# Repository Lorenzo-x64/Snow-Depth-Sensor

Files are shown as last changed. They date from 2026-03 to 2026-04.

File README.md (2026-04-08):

<div align="center">

  # Snow Depth Sensor

</div>

<div align="center">
  <picture>
    <source media="(prefers-color-scheme: dark)" srcset="https://github.com/lorenzor0912/Projet-IT-Neige/blob/0a817e1d05e45fb6e63a99a292cdd9ac2ce48b34/ReadMe_IMG/It%20neige.svg" />
    Logo principal
  </picture>

  <p><strong>Solution autonome de mesure d'enneigement pour environnements extrêmes</strong></p>

  <p>
    
    
    
    
  </p>
</div>

---

## Table des matières

- [Vue d'ensemble](#vue-densemble)
- [Hardware](#hardware)
  - [Capteur Principal](#capteur-principal)
  - [Microcontrôleur](#microcontrôleur)
  - [Stockage](#stockage)
  - [Communications](#communications)
  - [Alimentation](#alimentation)
  - [Matériaux & Boîtier](#matériaux--boîtier)
- [Software](#software)
- [Installation & Déploiement](#installation--déploiement)
- [Licence](#licence)

---

## Vue d'ensemble

Station de mesure d'enneigement autonome conçue pour fonctionner dans des conditions climatiques (jusqu'à -30°C) et piloté à distance.

| Caractéristique | Spécification |
|---|---|
| Plage de mesure | 30 cm à 750 cm (7,5 m) |
| Résolution | +-1 cm |
| Température d'opération | -30°C à +50°C |
| Étanchéité | IP66 |
| Autonomie |  mois (mode normal) |
| Fréquence de mesure | Configurable (défaut : 1 heures) |
| Connectivité | LoRaWAN |
| Stockage local | Carte SD haute endurance |

---

## Hardware

### Capteur ultrasonique

**Modèle** : SEN0313 / A01NYUB ou (JSN-SR04T possible)

Capteur SEN0313

<details>
<summary>Spécifications techniques détaillées</summary>

**Caractéristiques**
- Type : Capteur ultrasonique étanche IP67
- Plage de mesure : 28 cm à 750 cm
- Résolution : 1 cm / Précision : ±1%
- Angle de détection : 70° (avec cône fourni)

**Électrique**
- Tension d'alimentation : 3,3 V à 5 V DC
- Consommation : <15 mA (actif) / <5 mA (veille)
- Interface : UART (9600 bps par défaut)

**Environnemental**
- Température d'opération : -15°C à +60°C
- Étanchéité : IP67 (immersion jusqu'à 1 m pendant 30 min)
- Résistance : poussière, brouillard, fumée

**Avantages**
- Mesure directe en UART (pas de calcul de temps de vol)
- Cône amovible pour optimiser la directivité
- Meilleure pénétration que les HC-SR04 classiques
- Alimentation flexible (3,3V–5V)

**Documentation**
- [Guide officiel DF Robot](https://www.dfrobot.com/product-1934.html)
- [Datasheet PDF](https://wiki.dfrobot.com/A01NYUB%20Waterproof%20Ultrasonic%20Sensor%20SKU:%20SEN0313)

</details>

---

### Microcontrôleur

**Référence suggérée** : ESP32-DevKitC ou ESP32-WROVER pour stockage PSRAM additionnel ou module basse consomation 

ATTENTION! NE SONT PAS RECCOMANDE DES MODULES TOUS EN UN STYLE HELTEC LILYGO OU WAVESHARE (problème de librairies constaté sur heltec pour nous par ex)

---

### Communications

Le système utilise des technologies basse consommation pour maximiser l'autonomie.

#### LoRaWAN (mode principal retenu)

- **Module** : RFM95W ou LILYGO T-Beam
- Très faible consommation (~20–50 mA en transmission)
- Portée longue distance (>10 km en terrain dégagé)
- Pas d'abonnement cellulaire, idéal pour mesures espacées (4h)
- Inconvénient : infrastructure gateway requise, débit limité

#### Meshtastic 

- Voir si intégration possible intéréssant car maillé

#### 4G/LTE (option alternative)

- **Module** : SIM7600E-H ou SIM800L
- Couverture étendue, débit élevé, géolocalisation GPS intégrée
- Consommation élevée (~100–500 mA) et coût d'abonnement (~10€/mois)

<details>
<summary>Tableau comparatif détaillé</summary>

| Critère | LoRaWAN | Meshtastic | 4G/LTE |
|---|---|---|---|
| Portée | 2–15 km | 5–50 km (maillé) | 10–20 km |
| Consommation | 🟢 Faible (20–50 mA) | 🟢 Faible (30–80 mA) | 🔴 Élevée (100–500 mA) |
| Coût opérationnel | 🟢 Gratuit | 🟢 Gratuit | 🔴 ~10€/mois |
| Infrastructure | 🟡 Gateway requis | 🟡 Multi-nœuds | 🟢 Existante |
| Latence | 🟡 Minutes | 🟡 Variable | 🟢 Temps réel |

</details>

**Recommandation** : LoRaWAN en priorité pour l'efficacité énergétique, Meshtastic pour les déploiements multi-stations en montagne.

---

### Stockage

**Solution** : Carte microSD haute endurance

- Fréquence de mesure : 1 toutes les heures
- Format : CSV avec timestamp + distance + température

---

### Alimentation

**Autonomie cible : 4 mois**

Mais réalistiquement infaisable sans panneau solaire et grosse batterie une grosse optimisation est a prévoir sur la partie code pour essayer de consomer le moins possible 

---

### Matériaux & Boîtier

Le boîtier doit résister à des conditions extrêmes : neige, UV, humidité, températures de -30°C, pendant 10 ans.

#### Comparatif des matériaux d'impression 3D

| Critère | ASA-CF | PETG-CF | PET | ABS | PLA | ASA (std) | PC | PETG (std) | Nylon (PA) |
|---|---|---|-----|-----|-----|---|----|---|---|
| Résistance au froid (-30°C) | 🟢🟢 | 🟢🟢 | 🟢 | 🟢 | 🔴🔴 | 🟢🟢 | 🟢🟢 | 🟢🟢 | 🟢🟢 |
| Durabilité UV (10 ans ext.) | 🟢🟢 | 🟢 | 🔴 | 🔴 | 🔴🔴 | 🟢🟢 | 🟡 | 🟡 | 🟡 |
| Résistance à l'humidité | 🟢🟢 | 🟢🟢 | 🟢 | 🟢 | 🔴 | 🟢🟢 | 🟡 | 🟢🟢 | 🔴 |
| Stabilité dimensionnelle | 🟢🟢 | 🟢🟢 | 🟢 | 🟡 | 🔴 | 🟢🟢 | 🟢 | 🟢🟢 | 🔴 |
| Facilité d'impression | 🔴 | 🔴 | 🟢 | 🟡 | 🟢🟢 | 🟡 | 🔴🔴 | 🟢🟢 | 🔴 |
| Résistance mécanique | 🟢🟢 | 🟢🟢 | 🟢 | 🟢 | 🟡 | 🟢 | 🟢🟢 | 🟢 | 🟢🟢 |

Légende : 🟢🟢 Excellent · 🟢 Bon · 🟡 Moyen · 🔴 Faible · 🔴🔴 À éviter

<details>
<summary>Notes techniques détaillées</summary>

**Résistance au froid**
- PLA : devient cassant en dessous de 0°C → **À ÉVITER**
- PC & Nylon : restent flexibles même à -30°C
- ASA/ASA-CF : température de fléchissement >100°C

**Durabilité UV**
- ASA & ASA-CF : meilleure résistance (usage automobile) — stabilisants UV intégrés, pas de jaunissement après 5+ ans
- PLA, ABS, PET : dégradation rapide (jaunissement, fragilisation en <1 an)
- Nylon : variable selon type (PA12 > PA6)

**Résistance à l'humidité**
- ASA-CF : ~0,3–0,5% (excellent)
- PETG : très hydrophobe (~0,2%)
- Nylon PA6 : jusqu'à 8% ⚠️ (gonflement, perte de rigidité)
- PLA : gonflement + perte de propriétés mécaniques

**Facilité d'impression**
- Facile (PLA, PETG) : plateau 50–60°C, pas d'enceinte requise
- Enceinte chauffée requise (ASA, ABS, PC, Nylon) : 40–60°C, plateau 80–110°C
- Matériaux CF : buse acier trempé ou rubis obligatoire (fibres abrasives)
- PC & Nylon : >250°C, séchage 6–12h à 70°C avant impression

</details>

---

## Software

Le 13/03 Premier code fonctionel a prévoir une implémentation d'ecran tactile et de module lorawan Ebyte

### Fonctionnalités prévues

- [ ] **Acquisition de données**
  - Lecture des données SEN0313 (valeur directe en cm via UART)
  - Timestamping précis (RTC DS3231 externe)
  - Moyennage sur N échantillons (filtrage bruit)
- [ ] **Gestion de l'énergie**
  - Deep sleep ESP32 entre mesures (4h)
  - Wake-up timer configurable
  - Surveillance batterie (ADC + diviseur pont)
- [ ] **Stockage**
  - Écriture CSV sur carte SD
  - Rotation logs automatique (fichiers journaliers)
  - Protection buffer en cas de coupure
- [ ] **Communication**
  - Envoi périodique via LoRaWAN ou Meshtastic
  - Protocole configuré selon gateway disponible
  - Retry logic avec backoff exponentiel (en gros c ton tel quand il se bloque c exponantiel)

---

## Installation & Déploiement

### Liste du matériel nécessaire

| Composant | Qté | Prix unitaire | Lien |
|---|-----|---|---|
| Capteur SEN0313 ou | 1 | ~30€ | [none](https://www..html) |
| ESP32-DevKitC | 1 | ~5€ | [none](https://www..com) |
| Module LoRa  | 1 | ~15–25€ | [none](https://www..fr) |
| Carte SD 8Go Industrial | 1 | ~13€ | [none](https://www..fr) |
| Batterie LiFePO4 12V 20Ah | 1 | ~100€ | [ none] |
| Boîtier ASA-CF (impression) | 1 | ~15€ (filament) | À imprimer |
| Connectique étanche | Divers | ~10€ | [none](https://fr.com) |
| **TOTAL** | | **~a calculer** | |

---

## Licence

Ce projet est sous licence **GNU General Public License v3.0** — voir le fichier [LICENSE](LICENSE) pour plus de détails.

---

<div align="center">

### Développé par

Logo Sti2D Labs

<p><strong>Merci!</strong></p>

</div>

<div align="right">
  <a href="#top">↑ Retour en haut</a>
</div>

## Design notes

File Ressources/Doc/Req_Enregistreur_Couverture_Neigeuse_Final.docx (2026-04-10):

<< requirement>>

Enregistrer et transmettre les mesures

Id=’1’

Text = « La durée d’enregistrement des données qui seront exploitées à des fins scientifiques sera de 4 mois »

<< requirement>>

Pérennité d’utilisation de la partie électronique

Id=’1.1’

Text = « la pérénnité doit être garantie pour 10 ans »

<< requirement>>

Acquérir des données

Id=’1.2’

Text = «l’acquisition doit être double et synchronisée»

<< requirement>>

Pérennité face au froid

Id=’1.1.1’

Text = « Protection en cas de chute de la température -30°C»

<< requirement>>

Acquérir le niveau d’enneigement

Id=’1.2.1’

Text = « Acquérir la hauteur de neige avec une précision de 1 mm »

<< requirement>>

Acquérir la position GPS

Id=’1.2.2’

Text = « longitude, latitude et altitude »

<<block>>

ESP32-WROOM-32E + capteur SEN0313

<<block>>

ESP32-WROOM-32E + capteur GPS

<< requirement>>

Stocker les mesures de hauteur de neige et la position GPS de l’enregistreur

Id=’1.2.3’

Text = « Le stockage des données sera réalisé sur une carte SD pour une durée de mesure de 4 mois »

<<block>>

Carte SD

Capacité : 64Go

<<satisfy>>

<<satisfy>>

<<satisfy>>

<<satisfy>>

Req [Paquetage] Diagramme d’exigences [Enregistreur couverture neigeuse]

<< requirement>>

Protéger l’électronique ‘sensible’ de l’humidité

Id=’1.1.2’

Text = « environnement sec, aucun liquide ne doit entrer en contact avec les composants électroniques -IP66»

<<satisfy>>

<< requirement>>

Autonomie

Id=’1.4’

Text = «4 mois»

<<block>>

Batterie

Capacité : 8 GWatt

<<satisfy>>

<<block>>

Module Arduino Carte SD

<<satisfy>>

« deriveReqt »

<< requirement>>

Pérennité de la capacité

Id=’1.5’

Text = « faible variation de la température ambiante »

<<refine>>

<<block>>

Boitier

Imprimer en 3D

<<satisfy>>

<< requirement>>

Stocker des données

Id=’1.3’

Text = « l’enregistrement doit pouvoir être immédiatement exploité numériquement »

« deriveReqt »

« deriveReqt »

<<block>>

Boitier

Imprimer en 3D

<<block>>

Boitier

Imprimer en 3D

<< requirement>>

Transmettre des données

Id=’1.6’

Text = «la transmission des données toutes les heures doit être possible via le réseau 4G»

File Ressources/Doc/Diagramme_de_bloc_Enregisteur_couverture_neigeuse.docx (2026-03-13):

Sen0313

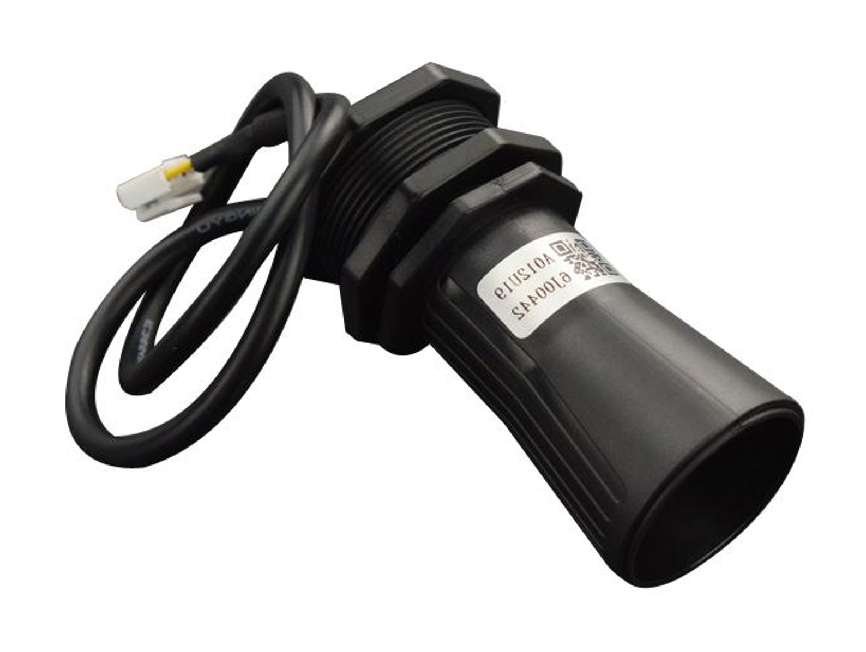
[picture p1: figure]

Module GPS

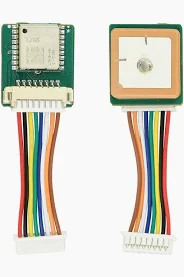
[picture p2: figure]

Batterie LiFePO4 12V 20Ah

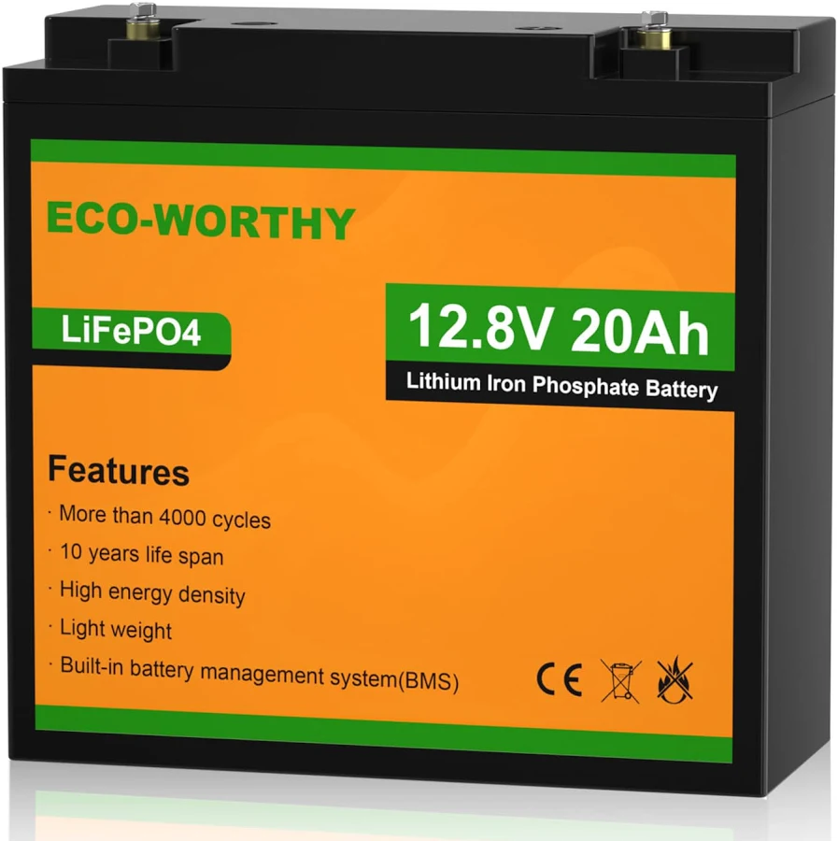
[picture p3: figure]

Heltec ESP32 S3

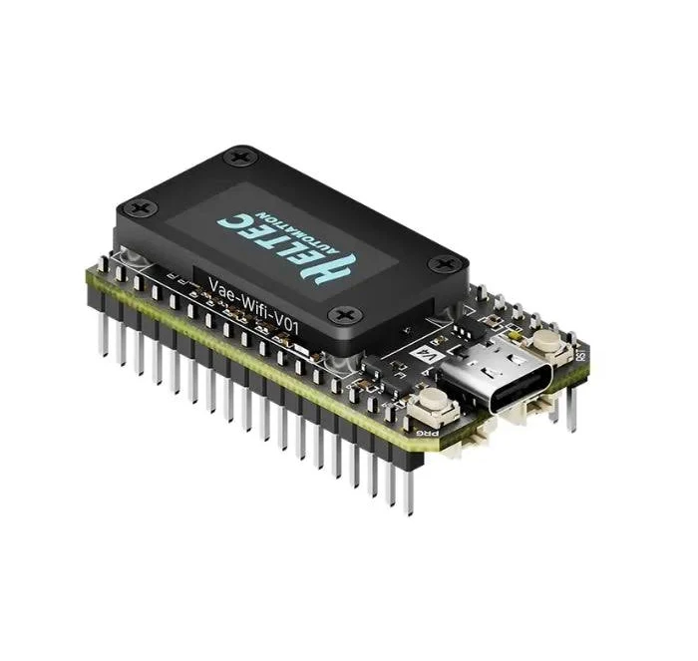
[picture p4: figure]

ESP32-DevKitC

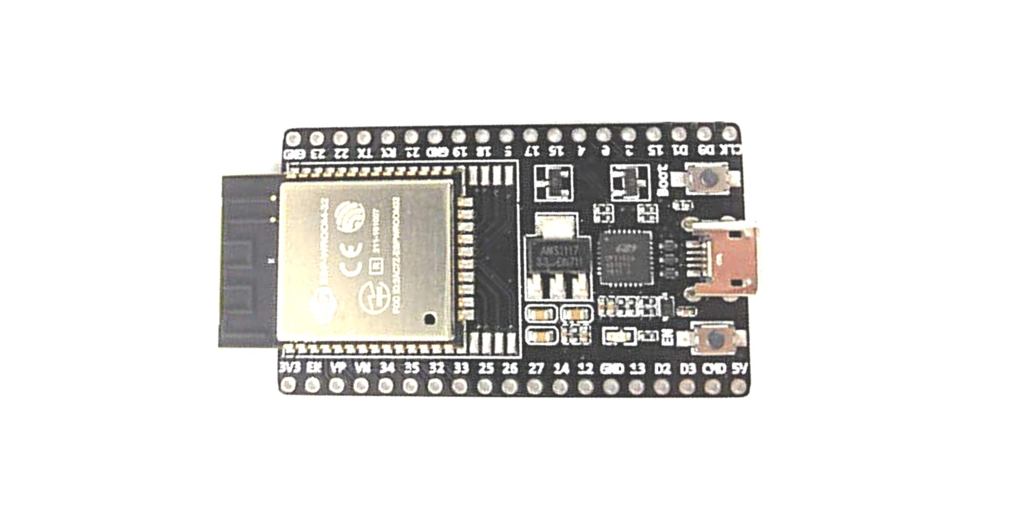
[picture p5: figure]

Diagramme de définition de bloc Enregistreur couverture neigeuse

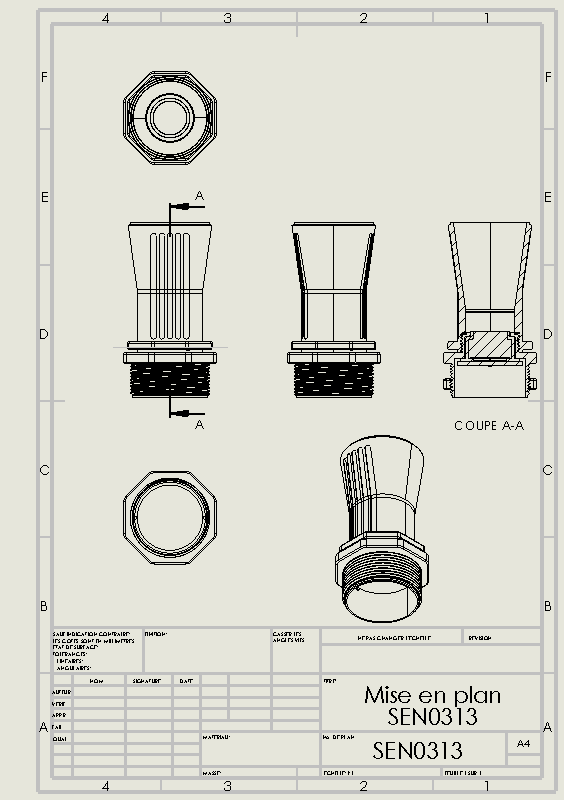
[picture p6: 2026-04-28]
3D Model/Mise en plan/SEN0313_Mise en plan image.PNG

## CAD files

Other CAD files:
3D Model/Mise en plan/SEN0313_Mise en plan.SLDDRW

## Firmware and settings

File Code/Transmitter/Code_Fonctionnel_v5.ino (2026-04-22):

/*
 * ╔══════════════════════════════════════════════════════════════════╗
 * ║   SNOW STATION — LoRa Transmitter v4  (WiFi Dashboard)           ║
 * ║   Board  : ESP32                                                 ║ 
 * ║   WiFi   : AP "snow sensor transmitter" / 1234567890             ║
 * ║   URL    : http://192.168.4.1                                    ║
 * ╚══════════════════════════════════════════════════════════════════╝
 *
 *  v3 → v4 additions:
 *    • BMI160 6-DOF IMU via I2C (SDA=21, SCL=22) — fall & impact detection
 *    • SD card full warning via LoRa
 *    • Fixed web UI map (Leaflet invalidateSize timing)
 *    • Dashboard IMU card + Alerts card + sidebar alerts count
 *    • /data JSON now includes bmi160_ready, fall_count, impact_count,
 *      last_alert, sd_nearly_full, accel data, fall_log_count
 *
 *  Dashboard panels
 *    1. Overview       — snow depth hero, GPS, LoRa TX, SD status, IMU
 *    2. GPS Map        — Leaflet / OSM live marker (fixed timing)
 *    3. LoRa TX        — transmission stats, last payload, alerts card
 *    4. SD Logger      — file status, row count, CSV download
 *    5. Accelerometer  — BMI160 live X/Y/Z, magnitude, peak, event log
 *    6. System         — RAM, Flash, CPU, uptime, WiFi AP info
 *
 *  Libraries required:
 *    TinyGPSPlus, LoRa_E220, SoftwareSerial, WiFi, WebServer, BMI160Gen
 */

#include <HardwareSerial.h>
#include <SoftwareSerial.h>
#include <TinyGPSPlus.h>
#include <SPI.h>
#include <SD.h>
#include <LoRa_E220.h>
#include <WiFi.h>
#include <WebServer.h>
#include <BMI160Gen.h>

// ═══════════════════════════════════════════════════
//  PIN DEFINITIONS
// ═══════════════════════════════════════════════════

#define GPS_RX_PIN      16
#define GPS_TX_PIN      17

#define US_RX_PIN        4

#define LORA_RX_PIN     13
#define LORA_TX_PIN     14
#define LORA_M0_PIN     26
#define LORA_M1_PIN     27
#define LORA_AUX_PIN    32

#define SD_MOSI_PIN     23
#define SD_MISO_PIN     19
#define SD_SCK_PIN      18
#define SD_CS_PIN        5

// ── BMI160 IMU (I2C) ──────────────────────────────
#define BMI160_I2C_ADDR  0x69
#define BMI160_SDA_PIN    21
#define BMI160_SCL_PIN    22

// ═══════════════════════════════════════════════════
//  CONFIG
// ═══════════════════════════════════════════════════

#define LOG_FILE          "/snowlog.csv"
#define LOG_INTERVAL_MS    2000
#define TIMEZONE_OFFSET_H  2
#define WIFI_AP_SSID       "snow sensor transmitter"
#define WIFI_AP_PASS       "1234567890"
#define MAX_HIST           60

// ── BMI160 thresholds ─────────────────────────────
#define BMI160_FALL_THRESHOLD_G      0.3f   // magnitude < 0.3g → free fall
#define BMI160_FALL_WINDOW_MS        150    // consecutive low-g window (ms)
#define BMI160_IMPACT_THRESHOLD_G    3.5f   // magnitude > 3.5g → impact
#define BMI160_ALERT_COOLDOWN_MS     10000  // 10 seconds between alerts
#define SD_FULL_CHECK_INTERVAL_MS    300000 // 5 minutes between SD full checks
#define SD_FULL_THRESHOLD_PCT        90.0f

// ── Accelerometer live tracking & logging ──────────
#define ACCEL_LOG_FILE              "/accellog.csv"
#define ACCEL_LOG_THRESHOLD_G       2.0f   // log event to SD when magnitude > this
#define ACCEL_LOG_MAX_ENTRIES       30     // in-memory ring buffer for web UI

// ── Fall detection event log ──────────────────────
#define FALL_LOG_FILE              "/falllog.csv"
#define FALL_LOG_MAX_ENTRIES       20

// ═══════════════════════════════════════════════════
//  OBJECTS
// ═══════════════════════════════════════════════════

TinyGPSPlus    gps;
HardwareSerial gpsSerial(2);
SoftwareSerial usSerial(US_RX_PIN, -1);
HardwareSerial loraSerial(1);
LoRa_E220      lora(&loraSerial, LORA_AUX_PIN, LORA_M0_PIN, LORA_M1_PIN);
WebServer      server(80);

// ═══════════════════════════════════════════════════
//  STATE
// ═══════════════════════════════════════════════════

float    distCm       = -1;
bool     sdReady      = false;
bool     loraReady    = false;
uint8_t  usBuf[4];
uint8_t  usIdx        = 0;
uint32_t loraLastTxMs = 0;
uint32_t loraCount    = 0;
uint32_t sdRowCount   = 0;
uint32_t lastReadMs   = 0;        // time of last valid ultrasonic reading
char     lastPayload[140] = "";   // last LoRa payload string

// ── BMI160 IMU state ─────────────────────────────
bool     bmi160Ready     = false;
uint32_t fallCount       = 0;
uint32_t impactCount     = 0;
uint32_t lastAlertTime   = 0;     // millis of last IMU alert (cooldown)
bool     inFreeFall      = false;
uint32_t freeFallStartMs = 0;
char     lastAlertType[20] = "---"; // "FALL", "IMPACT", or "SD_FULL"
char     lastAlertTs[22]   = "---"; // timestamp string

// ── Live accelerometer data ───────────────────────
float    liveAccelX  = 0;
float    liveAccelY  = 0;
float    liveAccelZ  = 0;
float    liveAccelMag = 0;

// ── Peak acceleration tracking ────────────────────
float    peakMag      = 0;
float    peakX        = 0;
float    peakY        = 0;
float    peakZ        = 0;
char     peakTs[22]   = "---";

// ── Acceleration event log (ring buffer + SD) ─────
struct AccelEvent {
  float  mag, ax, ay, az;
  char   ts[22];
};
AccelEvent accelLog[ACCEL_LOG_MAX_ENTRIES];
int accelLogHead  = 0;
int accelLogCount = 0;
uint32_t lastAccelLogMs = 0;       // throttle SD writes for accel events
#define ACCEL_LOG_COOLDOWN_MS     500  // minimum 500 ms between logged events

// ── Fall event log (ring buffer + SD) ─────────────
struct FallEvent {
  float  mag, ax, ay, az;
  uint32_t durationMs;
  char   ts[22];
};
FallEvent fallLog[FALL_LOG_MAX_ENTRIES];
int fallLogHead  = 0;
int fallLogCount = 0;

// ── SD full detection state ──────────────────────
bool     sdNearlyFull       = false;
bool     sdFullAlertSent    = false;
uint32_t lastSdFullCheckMs  = 0;

// in-memory circular history (60 entries, mirrors receiver pattern)
struct HistEntry {
  float  depth, lat, lon, alt, speed;
  int    sats;
  char   date[12];
  char   time_s[10];
};
HistEntry g_hist[MAX_HIST];
int g_histHead  = 0;
int g_histCount = 0;

// ═══════════════════════════════════════════════════
//  TIME HELPER
// ═══════════════════════════════════════════════════

void localTime(int &h, int &m, int &s, int &d, int &mo, int &y) {
  h  = gps.time.isValid() ? (int)gps.time.hour()   : 0;
  m  = gps.time.isValid() ? (int)gps.time.minute() : 0;
  s  = gps.time.isValid() ? (int)gps.time.second() : 0;
  d  = gps.date.isValid() ? (int)gps.date.day()    : 1;
  mo = gps.date.isValid() ? (int)gps.date.month()  : 1;
  y  = gps.date.isValid() ? (int)gps.date.year()   : 2000;

  if (!gps.time.isValid() || !gps.date.isValid()) return;

  h += TIMEZONE_OFFSET_H;

  if (h >= 24) {
    h -= 24; d += 1;
    int dim[] = {31,28,31,30,31,30,31,31,30,31,30,31};
    if ((y%4==0&&y%100!=0)||(y%400==0)) dim[1]=29;
    if (d > dim[mo-1]) { d=1; mo++; if (mo>12){mo=1;y++;} }
  }
  if (h < 0) {
    h += 24; d--;
    if (d < 1) {
      mo--;
      if (mo<1){mo=12;y--;}
      int dim[] = {31,28,31,30,31,30,31,31,30,31,30,31};
      if ((y%4==0&&y%100!=0)||(y%400==0)) dim[1]=29;
      d = dim[mo-1];
    }
  }
}

// helper: build "YYYY-MM-DD,HH:MM:SS" timestamp string
void buildTimestamp(char *buf, size_t len) {
  int h, m, s, d, mo, y;
  localTime(h, m, s, d, mo, y);
  snprintf(buf, len, "%04d-%02d-%02d,%02d:%02d:%02d", y, mo, d, h, m, s);
}

// ═══════════════════════════════════════════════════
//  BMI160 IMU — Fall & Impact Detection
// ═══════════════════════════════════════════════════

void sendAlertLoRa(const char *type) {
  if (!loraReady) return;

  char ts[24];
  buildTimestamp(ts, sizeof(ts));

  char msg[64];
  snprintf(msg, sizeof(msg), "ALERT:%s,%s", type, ts);

  lora.sendMessage(msg);
  loraCount++;

  strncpy(lastAlertType, type, sizeof(lastAlertType) - 1);
  strncpy(lastAlertTs, ts, sizeof(lastAlertTs) - 1);

  Serial.printf("[ IMU  ] LoRa alert sent: %s\n", msg);
}

void logAlertToSD(const char *type) {
  if (!sdReady) return;
  File f = SD.open(LOG_FILE, FILE_APPEND);
  if (!f) return;

  char ts[24];
  buildTimestamp(ts, sizeof(ts));

  f.printf("#ALERT:%s,%s\n", type, ts);
  f.close();
}

void logAccelEvent(float mag, float ax, float ay, float az) {
  // Store in in-memory ring buffer
  char ts[24];
  buildTimestamp(ts, sizeof(ts));

  AccelEvent& ev = accelLog[accelLogHead];
  ev.mag = mag; ev.ax = ax; ev.ay = ay; ev.az = az;
  strncpy(ev.ts, ts, sizeof(ev.ts) - 1);
  ev.ts[sizeof(ev.ts) - 1] = '\0';
  accelLogHead = (accelLogHead + 1) % ACCEL_LOG_MAX_ENTRIES;
  if (accelLogCount < ACCEL_LOG_MAX_ENTRIES) accelLogCount++;

  // Log to SD card
  if (!sdReady) return;
  File f = SD.open(ACCEL_LOG_FILE, FILE_APPEND);
  if (!f) return;
  f.printf("%s,%.3f,%.3f,%.3f,%.3f\n", ts, mag, ax, ay, az);
  f.close();
}

void logFallEvent(float mag, float ax, float ay, float az, uint32_t duration) {
  char ts[24];
  buildTimestamp(ts, sizeof(ts));

  FallEvent& ev = fallLog[fallLogHead];
  ev.mag = mag; ev.ax = ax; ev.ay = ay; ev.az = az;
  ev.durationMs = duration;
  strncpy(ev.ts, ts, sizeof(ev.ts) - 1);
  ev.ts[sizeof(ev.ts) - 1] = '\0';
  fallLogHead = (fallLogHead + 1) % FALL_LOG_MAX_ENTRIES;
  if (fallLogCount < FALL_LOG_MAX_ENTRIES) fallLogCount++;

  // Log to SD card
  if (!sdReady) return;
  File f = SD.open(FALL_LOG_FILE, FILE_APPEND);
  if (!f) return;
  f.printf("%s,%.3f,%u,%.3f,%.3f,%.3f\n", ts, mag, duration, ax, ay, az);
  f.close();
  Serial.printf("[ FALL ] Logged to SD: %.3f g, duration %u ms\n", mag, duration);
}

void checkBMI160() {
  if (!bmi160Ready) return;

  int rawX, rawY, rawZ;
  BMI160.readAccelerometer(rawX, rawY, rawZ);

  // Convert raw → g (±2g range: 16384 LSB/g)
  float ax = rawX / 16384.0f;
  float ay = rawY / 16384.0f;
  float az = rawZ / 16384.0f;
  float mag = sqrt(ax * ax + ay * ay + az * az);

  // Update live values
  liveAccelX  = ax;
  liveAccelY  = ay;
  liveAccelZ  = az;
  liveAccelMag = mag;

  // Track peak
  if (mag > peakMag) {
    peakMag = mag;
    peakX = ax;
    peakY = ay;
    peakZ = az;
    char ts[24];
    buildTimestamp(ts, sizeof(ts));
    strncpy(peakTs, ts, sizeof(peakTs) - 1);
    peakTs[sizeof(peakTs) - 1] = '\0';
  }

  uint32_t now = millis();

  // Cooldown check
  bool cooldownActive = (now - lastAlertTime) < BMI160_ALERT_COOLDOWN_MS;

  // ── Log big acceleration to SD (separate from alerts) ──
  if (mag > ACCEL_LOG_THRESHOLD_G && (now - lastAccelLogMs >= ACCEL_LOG_COOLDOWN_MS)) {
    lastAccelLogMs = now;
    logAccelEvent(mag, ax, ay, az);
    Serial.printf("[ ACCEL] Logged event: %.3f g (X=%.3f Y=%.3f Z=%.3f)\n", mag, ax, ay, az);
  }

  // ── Free-fall detection ──
  if (mag < BMI160_FALL_THRESHOLD_G) {
    if (!inFreeFall) {
      inFreeFall = true;
      freeFallStartMs = now;
    }
    // If free-fall sustained for the window and cooldown expired → alert
    if (inFreeFall && (now - freeFallStartMs >= BMI160_FALL_WINDOW_MS) && !cooldownActive) {
      uint32_t fallDur = now - freeFallStartMs;
      fallCount++;
      lastAlertTime = now;
      Serial.printf("[ IMU  ] ⚠ FREE FALL detected! magnitude=%.3f g (duration: %lu ms)\n", mag, fallDur);
      sendAlertLoRa("FALL");
      logAlertToSD("FALL");
      logFallEvent(mag, ax, ay, az, fallDur);
      inFreeFall = false;
    }
  } else {
    inFreeFall = false;
  }

  // ── Impact detection ──
  if (mag > BMI160_IMPACT_THRESHOLD_G && !cooldownActive) {
    impactCount++;
    lastAlertTime = now;
    Serial.printf("[ IMU  ] 💥 IMPACT detected! magnitude=%.2f g\n", mag);
    sendAlertLoRa("IMPACT");
    logAlertToSD("IMPACT");
  }
}

// ═══════════════════════════════════════════════════
//  SD FULL CHECK
// ═══════════════════════════════════════════════════

void checkSdFull() {
  if (!sdReady) return;
  uint32_t now = millis();
  if (now - lastSdFullCheckMs < SD_FULL_CHECK_INTERVAL_MS) return;
  lastSdFullCheckMs = now;

  uint64_t totalBytes = SD.totalBytes();
  uint64_t usedBytes  = SD.usedBytes();

  if (totalBytes == 0) return; // can't check

  float usedPct = (float)usedBytes / (float)totalBytes * 100.0f;

  if (usedPct > SD_FULL_THRESHOLD_PCT && !sdNearlyFull) {
    sdNearlyFull = true;
  }

  if (sdNearlyFull && !sdFullAlertSent) {
    sdFullAlertSent = true;

    char ts[24];
    buildTimestamp(ts, sizeof(ts));

    if (loraReady) {
      char msg[64];
      snprintf(msg, sizeof(msg), "ALERT:SD_FULL,%s", ts);
      lora.sendMessage(msg);
      loraCount++;
    }

    strncpy(lastAlertType, "SD_FULL", sizeof(lastAlertType) - 1);
    strncpy(lastAlertTs, ts, sizeof(lastAlertTs) - 1);

    Serial.printf("[ SD   ] ⚠ SD nearly full! %.1f%% used (%llu / %llu bytes)\n",
                  usedPct, usedBytes, totalBytes);
    Serial.printf("[ SD   ] LoRa alert sent: ALERT:SD_FULL,%s\n", ts);

    // Also log to SD
    File f = SD.open(LOG_FILE, FILE_APPEND);
    if (f) {
      f.printf("#ALERT:SD_FULL,%s\n", ts);
      f.close();
    }
  }
}

// ═══════════════════════════════════════════════════
//  EMBEDDED WEB APPLICATION  (flash / PROGMEM)
// ═══════════════════════════════════════════════════

static const char INDEX_HTML[] PROGMEM = R"HTMLEND(
<!DOCTYPE html>
<html lang="en">
<head>
<meta charset="UTF-8">
<meta name="viewport" content="width=device-width,initial-scale=1">
<title>Snow Sensor TX ❄</title>
<link rel="stylesheet" href="https://unpkg.com/leaflet@1.9.4/dist/leaflet.css"/>
<script src="https://unpkg.com/leaflet@1.9.4/dist/leaflet.js"></script>
<style>
@import url('https://fonts.googleapis.com/css2?family=Outfit:wght@300;400;500;600;700&display=swap');

:root {
  --bg:          #08080a;
  --bg2:         #0d0d10;
  --surface:     rgba(255,255,255,0.042);
  --surface2:    rgba(255,255,255,0.07);
  --border:      rgba(255,255,255,0.08);
  --border2:     rgba(255,255,255,0.14);
  --text:        #f0f0f5;
  --text-dim:    rgba(240,240,245,0.40);
  --text-mid:    rgba(240,240,245,0.68);
  --blue:        #0a84ff;
  --blue-soft:   rgba(10,132,255,0.15);
  --cyan:        #64d2ff;
  --green:       #30d158;
  --green-soft:  rgba(48,209,88,0.14);
  --yellow:      #ffd60a;
  --yellow-soft: rgba(255,214,10,0.13);
  --red:         #ff453a;
  --red-soft:    rgba(255,69,58,0.13);
  --orange:      #ff9f0a;
  --orange-soft: rgba(255,159,10,0.13);
  --sidebar-w:   220px;
  --r:           18px;
}

*,*::before,*::after{box-sizing:border-box;margin:0;padding:0}
html,body{height:100%;background:var(--bg);color:var(--text);
  font-family:'Outfit',-apple-system,BlinkMacSystemFont,'Helvetica Neue',sans-serif;
  font-size:15px;-webkit-font-smoothing:antialiased;overflow:hidden}

body::before{content:'';position:fixed;inset:0;
  background-image:url("data:image/svg+xml,%3Csvg viewBox='0 0 200 200' xmlns='http://www.w3.org/2000/svg'%3E%3Cfilter id='n'%3E%3CfeTurbulence type='fractalNoise' baseFrequency='0.75' numOctaves='4' stitchTiles='stitch'/%3E%3C/filter%3E%3Crect width='100%25' height='100%25' filter='url(%23n)' opacity='0.025'/%3E%3C/svg%3E");
  background-size:200px;pointer-events:none;z-index:0}

.layout{display:flex;height:100vh;position:relative;z-index:1}

.sidebar{
  width:var(--sidebar-w);flex-shrink:0;
  background:rgba(10,10,13,0.95);border-right:1px solid var(--border);
  display:flex;flex-direction:column;
  backdrop-filter:blur(20px);-webkit-backdrop-filter:blur(20px);z-index:10}

.sidebar-logo{
  padding:22px 20px 18px;border-bottom:1px solid var(--border);
  display:flex;align-items:center;gap:12px}
.logo-icon{font-size:22px;line-height:1;
  filter:drop-shadow(0 0 8px rgba(100,210,255,0.55));
  animation:spinSlow 14s linear infinite}
@keyframes spinSlow{to{transform:rotate(360deg)}}
.logo-title{font-size:15px;font-weight:600;letter-spacing:-0.2px}
.logo-sub{font-size:10px;color:var(--text-dim);letter-spacing:0.8px;text-transform:uppercase;margin-top:1px}

.nav{flex:1;padding:12px 10px;display:flex;flex-direction:column;gap:4px}
.nav-item{
  display:flex;align-items:center;gap:12px;padding:10px 12px;border-radius:12px;
  cursor:pointer;transition:all 0.18s ease;color:var(--text-dim);
  font-size:14px;font-weight:500;border:1px solid transparent;user-select:none}
.nav-item:hover{background:var(--surface2);color:var(--text-mid)}
.nav-item.active{background:var(--blue-soft);border-color:rgba(10,132,255,0.25);color:var(--blue)}
.nav-icon{font-size:17px;width:22px;text-align:center;flex-shrink:0}
.nav-label{flex:1}

.sidebar-footer{
  padding:16px 14px;border-top:1px solid var(--border);
  font-size:11px;color:var(--text-dim)}
.sidebar-footer .sf-row{display:flex;justify-content:space-between;margin-bottom:4px}
.sf-val{color:var(--text-mid);font-weight:500}

.content{flex:1;display:flex;flex-direction:column;overflow:hidden}
.topbar{
  display:flex;align-items:center;justify-content:space-between;
  padding:16px 28px;border-bottom:1px solid var(--border);
  background:rgba(8,8,10,0.88);backdrop-filter:blur(20px);
  -webkit-backdrop-filter:blur(20px);flex-shrink:0}
.topbar-title{font-size:16px;font-weight:600;letter-spacing:-0.2px}
.topbar-sub{font-size:11px;color:var(--text-dim);margin-top:2px;text-transform:uppercase;letter-spacing:0.7px}

.live-badge{
  display:flex;align-items:center;gap:8px;padding:6px 14px;
  background:var(--surface);border:1px solid var(--border);
  border-radius:100px;font-size:12px;font-weight:500;color:var(--text-mid);transition:all 0.4s}
.live-badge.on{background:var(--green-soft);border-color:rgba(48,209,88,0.35);color:var(--green)}
.live-dot{width:7px;height:7px;border-radius:50%;background:var(--text-dim);transition:all 0.4s}
.live-badge.on .live-dot{background:var(--green);box-shadow:0 0 6px var(--green);animation:pulse 2s infinite}
@keyframes pulse{0%,100%{opacity:1}50%{opacity:.35}}

.panels{flex:1;overflow-y:auto;overflow-x:hidden;scroll-behavior:smooth}
.panels::-webkit-scrollbar{width:5px}
.panels::-webkit-scrollbar-track{background:transparent}
.panels::-webkit-scrollbar-thumb{background:var(--border2);border-radius:3px}

.panel{display:none;padding:26px 28px 80px;animation:fadeIn 0.25s ease}
.panel.active{display:block}
@keyframes fadeIn{from{opacity:0;transform:translateY(6px)}to{opacity:1;transform:translateY(0)}}

.section-title{
  font-size:11px;font-weight:600;letter-spacing:1.5px;text-transform:uppercase;
  color:var(--text-dim);margin-bottom:18px;display:flex;align-items:center;gap:8px}
.section-title::after{content:'';flex:1;height:1px;background:var(--border)}

.card{
  background:var(--surface);border:1px solid var(--border);border-radius:var(--r);
  padding:20px 22px;transition:border-color 0.25s,transform 0.18s;
  position:relative;overflow:hidden}
.card:hover{border-color:var(--border2);transform:translateY(-1px)}
.card::before{content:'';position:absolute;top:0;left:0;right:0;height:2px;
  border-radius:2px 2px 0 0;background:transparent;transition:background 0.3s}
.card.c-blue::before  {background:linear-gradient(90deg,var(--blue),transparent)}
.card.c-green::before {background:linear-gradient(90deg,var(--green),transparent)}
.card.c-cyan::before  {background:linear-gradient(90deg,var(--cyan),transparent)}
.card.c-yellow::before{background:linear-gradient(90deg,var(--yellow),transparent)}
.card.c-orange::before{background:linear-gradient(90deg,var(--orange),transparent)}
.card.c-red::before   {background:linear-gradient(90deg,var(--red),transparent)}

.card-label{font-size:11px;font-weight:600;letter-spacing:1.3px;text-transform:uppercase;
  color:var(--text-dim);margin-bottom:14px;display:flex;align-items:center;gap:6px}
.card-icon{font-size:14px}
.card-value{font-size:30px;font-weight:300;letter-spacing:-1.2px;line-height:1;margin-bottom:4px}
.card-value .unit{font-size:15px;font-weight:400;color:var(--text-dim);margin-left:3px}
.card-sub{font-size:12px;color:var(--text-dim);margin-top:8px}

.grid{display:grid;grid-template-columns:repeat(auto-fill,minmax(240px,1fr));gap:14px}
.col-2{grid-column:span 2}

.hero{
  background:linear-gradient(135deg,rgba(10,132,255,0.11) 0%,rgba(100,210,255,0.05) 50%,transparent 100%);
  border:1px solid rgba(10,132,255,0.22);border-radius:var(--r);
  padding:32px 36px;display:flex;align-items:center;justify-content:space-between;
  gap:20px;margin-bottom:22px;position:relative;overflow:hidden}
.hero::after{content:'❄';position:absolute;right:-15px;bottom:-25px;
  font-size:150px;opacity:0.04;pointer-events:none}
.hero-lbl{font-size:11px;font-weight:600;letter-spacing:1.5px;text-transform:uppercase;
  color:var(--blue);margin-bottom:8px}
.hero-val{font-size:68px;font-weight:300;letter-spacing:-4px;line-height:1}
.hero-val span{font-size:26px;font-weight:400;color:var(--text-mid);letter-spacing:0;margin-left:3px}
.hero-sub{font-size:18px;color:var(--text-dim);margin-top:6px;font-weight:400}
.hero-meta{text-align:right}
.hero-meta-row{font-size:13px;color:var(--text-dim);margin-bottom:5px}
.hero-meta-row strong{color:var(--text-mid);font-weight:500}

.last-rx{
  display:flex;align-items:center;justify-content:space-between;
  padding:10px 18px;background:var(--surface);border:1px solid var(--border);
  border-radius:10px;margin-bottom:20px;font-size:13px;color:var(--text-dim)}
.last-rx strong{color:var(--text-mid);font-weight:500}
.rx-age{font-size:12px}
.rx-age.fresh{color:var(--green)}.rx-age.stale{color:var(--yellow)}.rx-age.old{color:var(--red)}

.coords-grid{display:grid;grid-template-columns:1fr 1fr;gap:16px;margin-top:4px}
.coord-lbl{font-size:10px;color:var(--text-dim);text-transform:uppercase;letter-spacing:1px;margin-bottom:5px}
.coord-val{font-size:22px;font-weight:400;letter-spacing:-.3px;font-variant-numeric:tabular-nums}
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
void loop() {
  server.handleClient();   // serve WiFi requests first

  readGPS();
  readUltrasonic();

  // IMU check on every loop iteration for responsiveness
  checkBMI160();

  static unsigned long lastRun = 0;
  if (millis() - lastRun >= LOG_INTERVAL_MS) {
    lastRun = millis();
    printReport();
    logToSD();
    transmitLoRa();
  }
}

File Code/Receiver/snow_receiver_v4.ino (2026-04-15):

/*
 * ╔══════════════════════════════════════════════════════════════════╗
 * ║   SNOW STATION — LoRa Receiver v4                              ║
 * ║   Board  : Heltec WiFi LoRa 32 V3  (SX1262 onboard)           ║
 * ║   WiFi   : STA → ESP_84CA80  (open / no password)             ║
 * ║   Fallback AP : Station-Neige / 1234                          ║
 * ║   URL    : http://<ip>  or  http://stationneige.local         ║
 * ╚══════════════════════════════════════════════════════════════════╝
 *
 *  Required library (Arduino Library Manager):
 *    • RadioLib  by Jan Gromeš
 *
 *  Board package:
 *    • "Heltec ESP32 Series Dev-boards" → Heltec WiFi LoRa 32(V3)
 *
 *  Features:
 *    1. Live dashboard  — snow depth, GPS, signal quality
 *    2. LoRa scanner    — sweep 850–870 MHz, plot RSSI
 *    3. Frequency tuner — slide to 868 MHz EU band + apply
 *    4. GPS map         — Leaflet / OSM live marker
 *    5. Data log        — table of last 60 packets + CSV download
 */

#include <Arduino.h>
#include <SPI.h>
#include <RadioLib.h>
#include <WiFi.h>
#include <WebServer.h>
#include <ESPmDNS.h>

// ═══════════════════════════════════════════════════════
//  HELTEC V3 — ONBOARD SX1262 PIN MAP
// ═══════════════════════════════════════════════════════
#define LORA_SCK      9
#define LORA_MISO    11
#define LORA_MOSI    10
#define LORA_CS       8
#define LORA_RST     12
#define LORA_DIO1    14
#define LORA_BUSY    13
#define VEXT_PIN     36   // LOW = Vext rail ON
#define LED_PIN      35

// ═══════════════════════════════════════════════════════
//  WIFI
// ═══════════════════════════════════════════════════════
#define WIFI_STA_SSID   "ESP_84CA80"
#define WIFI_STA_PASS   ""            // open network
#define WIFI_AP_SSID    "Station-Neige"
#define WIFI_AP_PASS    "1234"
#define WIFI_TIMEOUT_MS 12000

bool wifiIsAP = false;   // true when running as fallback AP

// ═══════════════════════════════════════════════════════
//  LORA DEFAULTS
// ═══════════════════════════════════════════════════════
float   g_freq      = 868.125f;  // EU 868 default; set to 850.125 for E220 ch.0
#define LORA_BW      125.0
#define LORA_SF      9
#define LORA_CR      5
#define LORA_PREAMBLE 10
#define LORA_SYNC    0x12   // private LoRa (non-LoRaWAN)
#define LORA_POWER   22

// ═══════════════════════════════════════════════════════
//  CURRENT PACKET
// ═══════════════════════════════════════════════════════
struct SnowPacket {
  float    lat = 0, lon = 0, alt = 0, speed = 0, depth = -1;
  int      sats = 0;
  float    hdop = 0, snr = 0;
  int      rssi = 0;
  char     date[12]   = "--";
  char     time_s[10] = "--";
  char     raw[128]   = "";
  uint32_t lastMs     = 0;
  uint32_t count      = 0;
  bool     valid      = false;
} g_pkt;

// ═══════════════════════════════════════════════════════
//  PACKET HISTORY  (circular buffer, 60 entries)
// ═══════════════════════════════════════════════════════
#define MAX_HIST 60
struct HistEntry {
  float lat, lon, alt, speed, depth;
  int   sats, rssi;
  float snr;
  char  date[12];
  char  time_s[10];
};
HistEntry g_hist[MAX_HIST];
int  g_histHead  = 0;
int  g_histCount = 0;

// ═══════════════════════════════════════════════════════
//  SCANNER
//  Sweep 850–870 MHz, 1 MHz steps → 21 points
// ═══════════════════════════════════════════════════════
#define SCAN_N    21
#define SCAN_FROM 850.0f
#define SCAN_STEP   1.0f
#define SCAN_DWELL_MS 80   // ms per frequency

struct ScanPt { float freq; float rssi; };
ScanPt g_scan[SCAN_N];
bool   g_scanDone   = false;
bool   g_scanning   = false;

// ═══════════════════════════════════════════════════════
//  OBJECTS
// ═══════════════════════════════════════════════════════
SPIClass  loraSPI(FSPI);
SX1262    radio = new Module(LORA_CS, LORA_DIO1, LORA_RST, LORA_BUSY, loraSPI);
WebServer server(80);

// ═══════════════════════════════════════════════════════
//  FORWARD DECLARATIONS
// ═══════════════════════════════════════════════════════
void checkLoRa();
void parsePayload(const String& s);
bool radioInit(float freq);
void radioRxRestart();
void doScan();

void handleRoot();
void handleData();
void handleScan();
void handleSetFreq();
void handleHistory();
void handleDownload();
void handleNotFound();

// ═══════════════════════════════════════════════════════
//  EMBEDDED WEB APPLICATION  (stored in flash)
// ═══════════════════════════════════════════════════════
static const char INDEX_HTML[] PROGMEM = R"HTMLEND(
<!DOCTYPE html>
<html lang="fr">
<head>
<meta charset="UTF-8">
<meta name="viewport" content="width=device-width,initial-scale=1">
<title>Station Neige ❄</title>
<link rel="stylesheet" href="https://unpkg.com/leaflet@1.9.4/dist/leaflet.css"/>
<script src="https://unpkg.com/leaflet@1.9.4/dist/leaflet.js"></script>
<style>
@import url('https://fonts.googleapis.com/css2?family=Outfit:wght@300;400;500;600;700&display=swap');

:root {
  --bg:          #08080a;
  --bg2:         #0d0d10;
  --surface:     rgba(255,255,255,0.042);
  --surface2:    rgba(255,255,255,0.07);
  --border:      rgba(255,255,255,0.08);
  --border2:     rgba(255,255,255,0.14);
  --text:        #f0f0f5;
  --text-dim:    rgba(240,240,245,0.40);
  --text-mid:    rgba(240,240,245,0.68);
  --blue:        #0a84ff;
  --blue-soft:   rgba(10,132,255,0.15);
  --cyan:        #64d2ff;
  --green:       #30d158;
  --green-soft:  rgba(48,209,88,0.14);
  --yellow:      #ffd60a;
  --yellow-soft: rgba(255,214,10,0.13);
  --red:         #ff453a;
  --red-soft:    rgba(255,69,58,0.13);
  --orange:      #ff9f0a;
  --sidebar-w:   220px;
  --r:           18px;
}

*,*::before,*::after{box-sizing:border-box;margin:0;padding:0}
html,body{height:100%;background:var(--bg);color:var(--text);
  font-family:'Outfit',-apple-system,BlinkMacSystemFont,'Helvetica Neue',sans-serif;
  font-size:15px;-webkit-font-smoothing:antialiased;overflow:hidden}

/* grain */
body::before{content:'';position:fixed;inset:0;
  background-image:url("data:image/svg+xml,%3Csvg viewBox='0 0 200 200' xmlns='http://www.w3.org/2000/svg'%3E%3Cfilter id='n'%3E%3CfeTurbulence type='fractalNoise' baseFrequency='0.75' numOctaves='4' stitchTiles='stitch'/%3E%3C/filter%3E%3Crect width='100%25' height='100%25' filter='url(%23n)' opacity='0.025'/%3E%3C/svg%3E");
  background-size:200px;pointer-events:none;z-index:0}

/* ── LAYOUT ──────────────────────────────────── */
.layout{display:flex;height:100vh;position:relative;z-index:1}

/* ── SIDEBAR ──────────────────────────────────── */
.sidebar{
  width:var(--sidebar-w);
  flex-shrink:0;
  background:rgba(10,10,13,0.95);
  border-right:1px solid var(--border);
  display:flex;flex-direction:column;
  backdrop-filter:blur(20px);
  -webkit-backdrop-filter:blur(20px);
  z-index:10;
}

.sidebar-logo{
  padding:22px 20px 18px;
  border-bottom:1px solid var(--border);
  display:flex;align-items:center;gap:12px;
}
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

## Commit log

2026-03-06 Add new resource link for Adafruit microSD SPI SDIO
2026-03-20 Add Heltec ESP32 package link to resources
2026-03-20 Fix URL for Heltec ESP32 package resource
2026-04-02 Refactor advantages and material recommendations
    Removed checkmarks from advantages section and updated recommendations for outdoor materials.
2026-04-08 Revise material list and remove ASCII art
    Updated links to 'none' and removed ASCII art.
2026-04-08 Update model description for ultrasonic sensor
2026-04-08 Revise README with updated specs and calculations
    Updated specifications and recommendations for microcontroller and communication modules. Adjusted power consumption calculations and material recommendations for outdoor use.
2026-04-14 Add snow station project code
    Initial commit of the snow station project code, including GPS, ultrasonic, LoRa, and SD logging functionalities.
